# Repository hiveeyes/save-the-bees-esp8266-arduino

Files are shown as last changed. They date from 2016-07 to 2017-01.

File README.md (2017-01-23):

# Save the Bees! for ESP8266 (WeMos D1 Mini)

## Introduction
<!--A brief description of the purpose and functionality of the project.-->
*Save the Bees!* is an Open Source project that is used to track the status of a beehive through a microcontroller and some sensors.

The following version is the entry-level one and it is intended for the the ESP8266 microcontroller running the Arduino framework.

Following the steps of this guide you can start quickly tracking your beehive and get the status of it.

## Requirements
<!--A list of all system requirements and required third-party components.-->

### Hardware
This is your shopping list:

- Board: [WeMos D1 Mini](https://www.wemos.cc/product/d1-mini.html)
- Analog Multiplexer: [CD74HC4052E](http://www.ti.com/lit/gpn/CD74HC4052) by Texas Instruments
- RTC module: either [DS1307](https://www.maximintegrated.com/en/products/digital/real-time-clocks/DS1307.html) or [DS3231](https://www.maximintegrated.com/en/products/digital/real-time-clocks/DS3231.html) based modules are compatible
- Temperature module: [AM2315](http://www.aosong.com/en/products/details.asp?id=121) by Aosong
- Compression load cells: 4x [FC2231-0000-0100-L](http://www.te.com/usa-en/product-CAT-FSE0001.html) by Measurement Specialities

### Software
The Software used for this project and the source code of the project itself are open source and then free to use:

- USBtoUART drivers
- [PlatformIO](http://platformio.org/) IDE or [Arduino](https://www.arduino.cc/) IDE with support for the WeMos D1 Mini board
- Adafruit AM2315 [Library](https://github.com/adafruit/Adafruit_AM2315)
- Adafruit RTClib [Library](https://github.com/adafruit/RTClib)
- PubSubClient [Library](https://github.com/uberdriven/pubsubclient), an Arduino client for MQTT protocol, modified with an increased packet size of 512 bytes
- Arduino JSON [Library](https://github.com/bblanchon/ArduinoJson)

## Installation & Configuration
<!--Step-by-step instructions, with proper punctuation, on how to install and configure the project.-->
In order to compile the script and upload it to the board, you have to follow the next steps:

### 1) Download the CH340 USB to UART drivers
The drivers are necessary to communicate with the serial port on a device via USB. You can download the them from [here](https://www.wemos.cc/downloads/) for Windows or macOS. GNU/Linux systems do not need any driver.

NOTE: If you have **macOS Sierra** (10.12.x) and you never installed any CH34x drivers before, you must download [this](http://blog.sengotta.net/wp-content/uploads/2015/11/CH34x_Install_V1.3.zip) driver, otherwise if you had already a previous version installed follow [this](https://github.com/adrianmihalko/ch340g-ch34g-ch34x-mac-os-x-driver) guide.

To be sure that your drivers are currently working, connect the WeMos D1 Mini to your computer via USB, open a terminal window and type `ls /dev/cu.*` (in macOS). You should find between the devices connected something similar to `/dev/cu.wchusbserial1410`.

### 2) Install Python
Python is necessary because the compiler for the ESP8266 (on which the WeMos D1 mini is based) runs a set of commands in Python. Python comes by default with macOS and GNU/Linux, to check if it is installed, just open a terminal window and digit `python -V`. While Windows users should [download](https://www.python.org/downloads/) and install it manually.

### 3) Set up your IDE
There are two main options where to edit the script, send the code to the board and monitor the serial output: Arduino IDE or PlatformIO.

#### PlatformIO
PlatformIO is an open source ecosystem for IoT development. It brings many useful features as code auto completion, a smart library manager and others. Is is available as *core* version (command line interface) and as a plugin for many popular IDEs and text editors. It supports natively many platforms, frameworks and boards. The easiest way to start with PlatformIO is [download](http://platformio.org/get-started/ide) the PlatformIO IDE (Atom text editor with already the PlatformIO core and plugins installed).

#### Arduino IDE
The Arduino IDE is the native software for developing programs for Arduino and compatible boards.

- Download it for [Windows](https://www.arduino.cc/en/Guide/Windows), [macOS](https://www.arduino.cc/en/Guide/MacOSX) or [GNU/Linux](https://www.arduino.cc/en/Guide/Linux)
- Once downloaded and installed, open the `preferences` tab, and into the `Additional Board Manager` field insert `http://arduino.esp8266.com/stable/package_esp8266com_index.json`. The field can support multiple URLs separated with commas
- Open `Tools` → `Board: xxx` → `Boards Manager` and install *esp8266* by *ESP8266 Community*
- Select the right board:  `Tools` → `Board: xxx` and select `WeMos D1 R2 Mini`
- Select the right upload speed: `Tools` → `Upload Speed` → `115200`

### 4) Install the required libraries

#### With PlatformIO
Platformio provides a very good [library manager](http://platformio.org/lib) and it is very easy add a new library for a project. Open Atom, then `PlatformIO` tab → `Terminal` → `Toggle` and type:

```
pio lib -g install 773
```
this command install the Adafruit AM2315 Library,

```
pio lib -g install 64
```
this command install the Arduino JSON library,

```
pio lib -g install 83
```
this command install the Adafruit RTClib Library,

```
pio lib -g install https://github.com/uberdriven/pubsubclient
```
this command install the PubSubClient modified library.

#### With Arduino IDE
First you should download the four libraries from GitHub, then open the Arduino IDE, `Sketch` tab → `Include Library` → `Add .ZIP library` and select the downloaded libs one by one. For an extended explanation, check the Arduino [guide](https://www.arduino.cc/en/Guide/Libraries) how to include libraries.

### 5) Connect the componets
Connect the components as in the Fritzing generated PDF schema in this repo.

NOTE: if you use a DS1307 RTC, you should provide it 5V, while for a DS3231 RTC it is enough use the 3.3V.

### 6) Flash the program on your board
TO-DO

Connect your WeMos D1 Mini to your computer via USB. Now you can copy and paste from this repository the last version of the code.

For now, the only two parameters you can modify are:

- the `SLEEP_TIME`, that is the number of seconds for 
- the model of RTC used
- the `ACCESS_POINT_PWD`, that is the password of the setup mode, the default one is *BeeHive91*

### 7) Create your device on relayr Dashboard

### 8) Insert your Wi-Fi and relayr credentials
Turn on the board into the Setup Mode. It will create a Wi-Fi Access Point called `BeeSetup` using both the 2.4GHz and the 5GHz frequency bands. From your computer connect to that network using the password defined in the step 6 of this document. Then open your browser and in the URL field digit `192.168.1.4` and connect. You will see the following page:

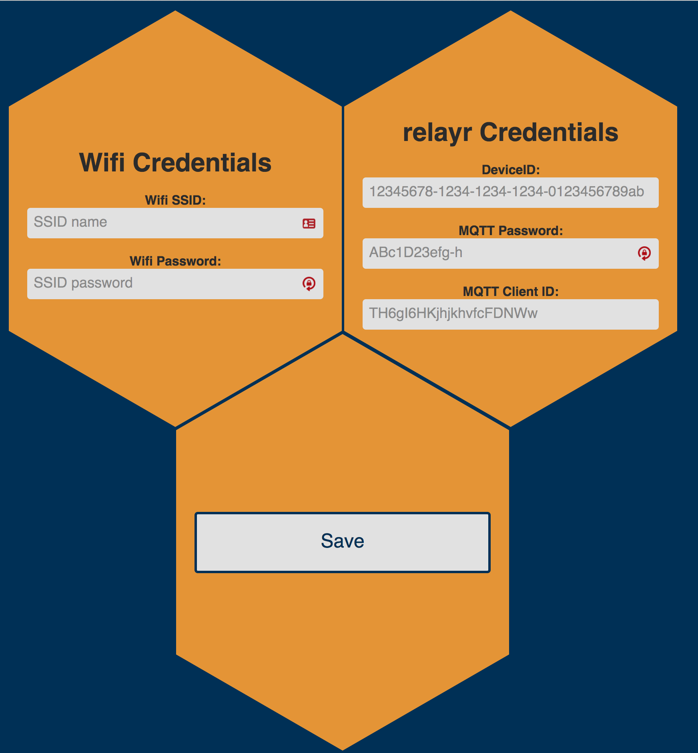
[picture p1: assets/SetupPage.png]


Enter first the Wi-Fi credentials of your Access Point connected to the Internet, then the relayr credentials you got from step 7 of this guide and finally press on the Save button. If in future you will have to change your parameters, just follow again this step.

### 9) Set the tare

Now digit in your browser the address `192.168.1.4/tare`. You will see the following page:

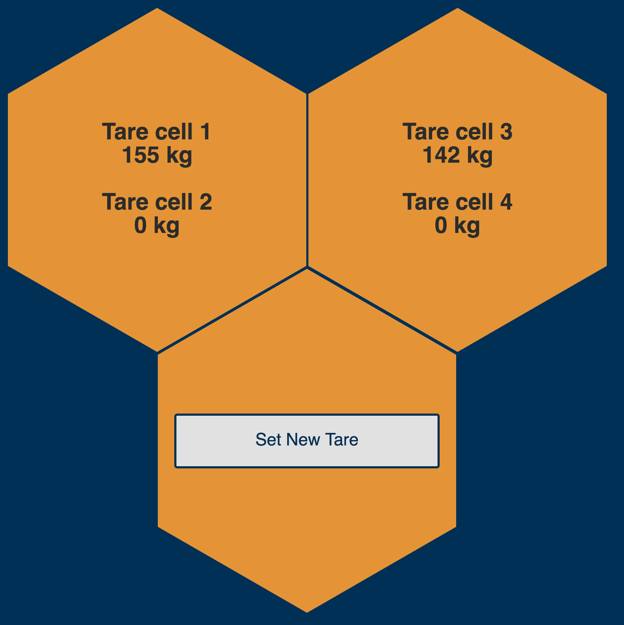
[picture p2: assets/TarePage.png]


When you will press the `Set New Tare` button the current weight on the loadcell will be considered the point zero.

### 10) (Optional) Display the beehive sensors readings with Grafana

## To-Do

- Add a switch to enter in setup mode easier
- Add configurations/commands/QoS support
- Build the base and hardware
- Add 5th loadcell support
- Add external ADC

## License
<!--The license under which the software will be released. Open-source projects MUST include the MIT License, and closed-source projects MUST include a proprietary license to be discussed with the Documentation team.
-->
The MIT License (MIT)
Copyright (c) 2017 relayr Inc., Riccardo Marconcini [riccardo DOT marconcini AT relayr DOT de](mailto:riccardo.marconcini@relayr.de)

Permission is hereby granted, free of charge, to any person obtaining a copy of this software and associated documentation files (the "Software"), to deal in the Software without restriction, including without limitation the rights to use, copy, modify, merge, publish, distribute, sublicense, and/or sell copies of the Software, and to permit persons to whom the Software is furnished to do so, subject to the following conditions:

The above copyright notice and this permission notice shall be included in all copies or substantial portions of the Software.

THE SOFTWARE IS PROVIDED "AS IS", WITHOUT WARRANTY OF ANY KIND, EXPRESS OR IMPLIED, INCLUDING BUT NOT LIMITED TO THE WARRANTIES OF MERCHANTABILITY, FITNESS FOR A PARTICULAR PURPOSE AND NONINFRINGEMENT. IN NO EVENT SHALL THE AUTHORS OR COPYRIGHT HOLDERS BE LIABLE FOR ANY CLAIM, DAMAGES OR OTHER LIABILITY, WHETHER IN AN ACTION OF CONTRACT, TORT OR OTHERWISE, ARISING FROM, OUT OF OR IN CONNECTION WITH THE SOFTWARE OR THE USE OR OTHER DEALINGS IN THE SOFTWARE.

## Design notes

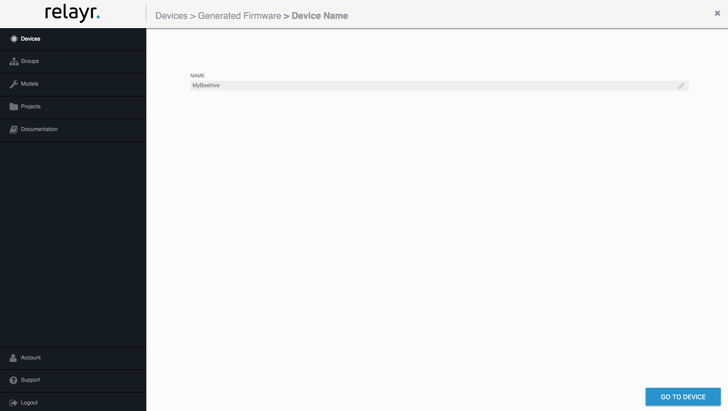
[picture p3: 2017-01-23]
assets/Schermata 2017-01-18 alle 18.39.31.png

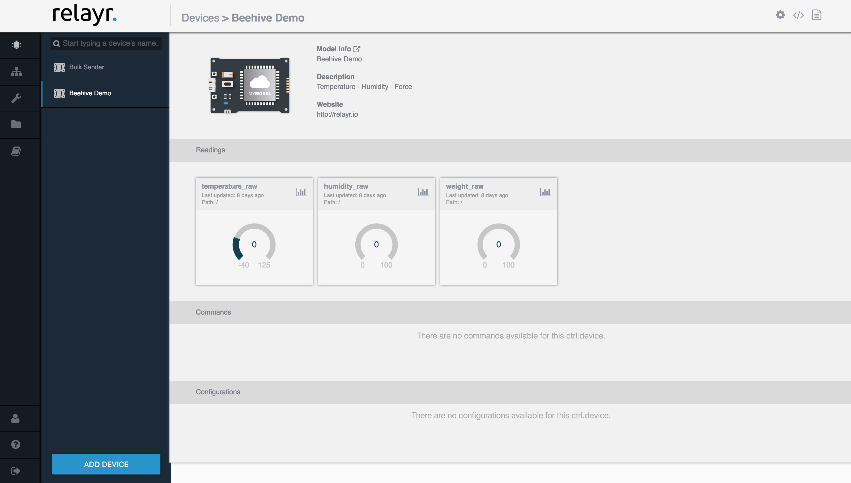
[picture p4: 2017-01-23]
assets/Schermata 2017-01-18 alle 18.28.16.png

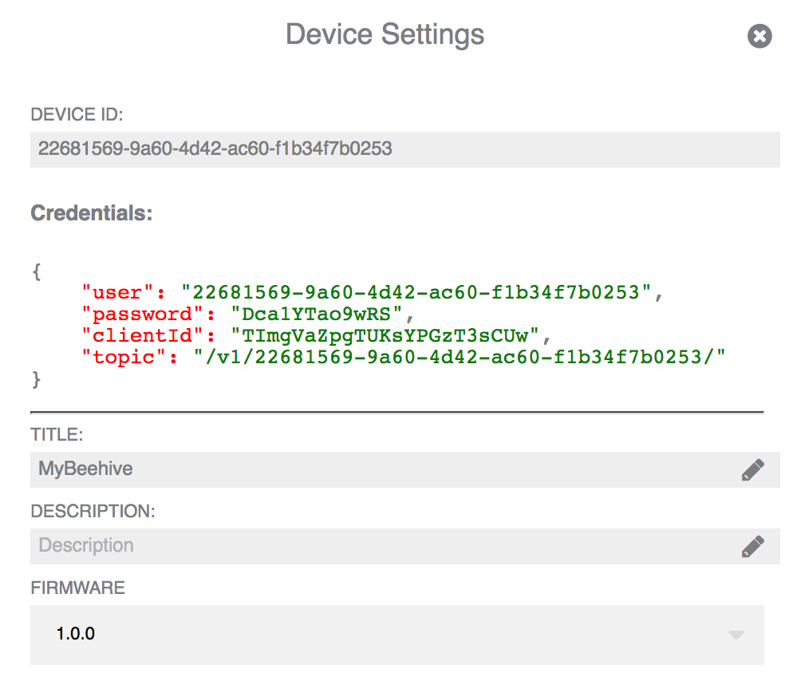
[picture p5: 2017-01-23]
assets/Schermata 2017-01-18 alle 18.40.48.png

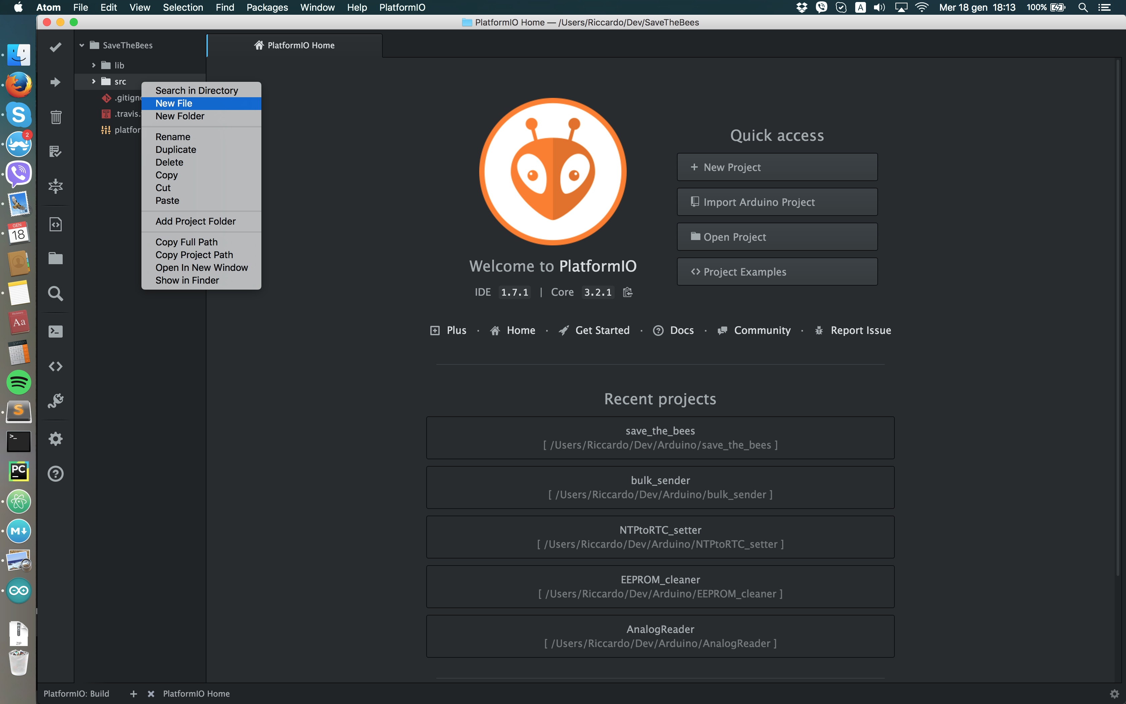
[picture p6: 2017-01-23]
assets/Schermata 2017-01-18 alle 18.13.08.png

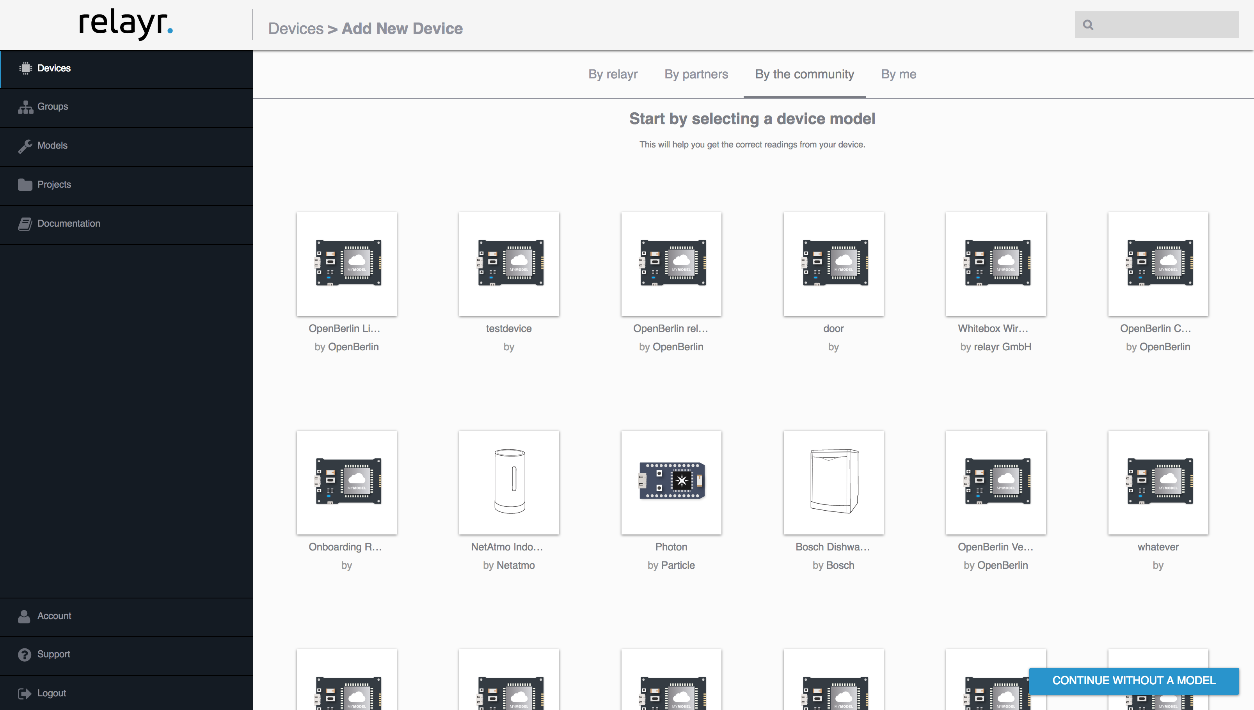
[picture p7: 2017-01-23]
assets/Schermata 2017-01-18 alle 18.37.14.png

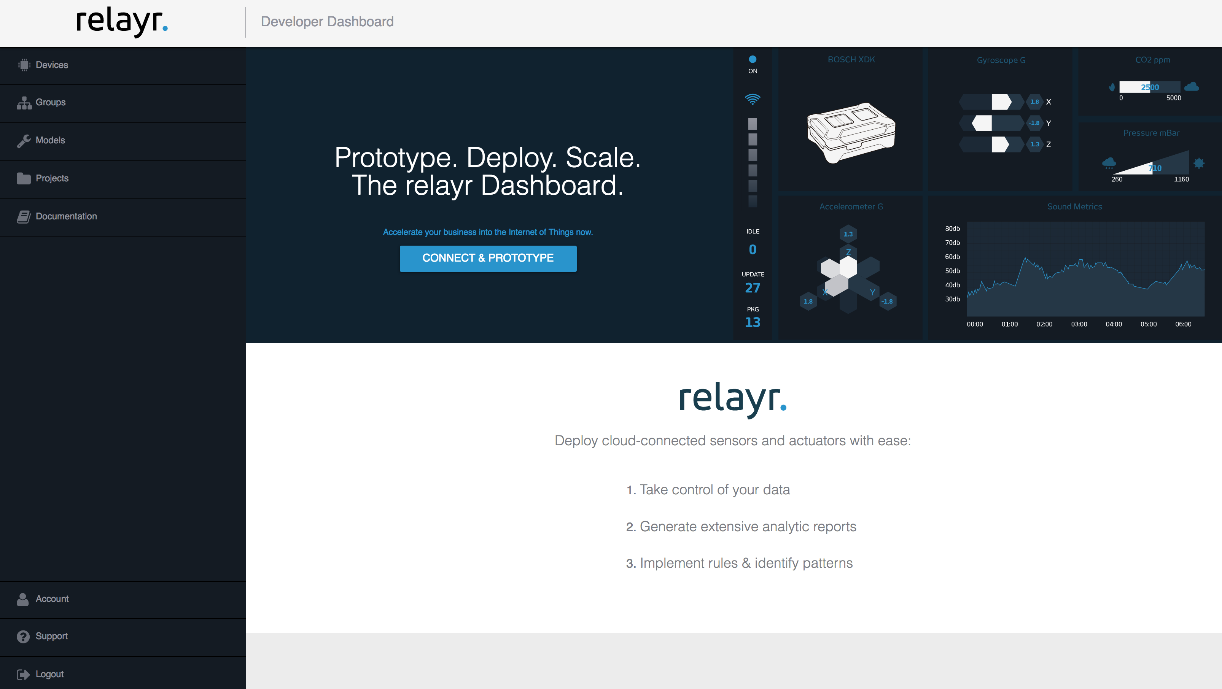
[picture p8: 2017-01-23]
assets/Schermata 2017-01-18 alle 18.27.46.png

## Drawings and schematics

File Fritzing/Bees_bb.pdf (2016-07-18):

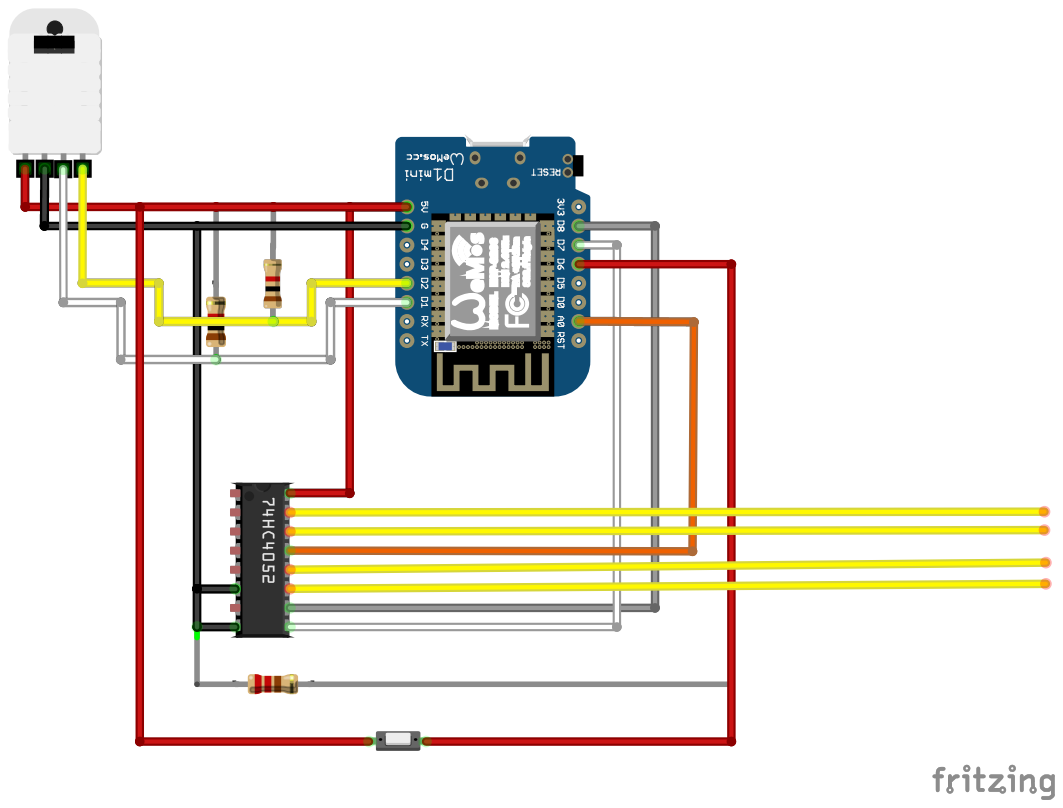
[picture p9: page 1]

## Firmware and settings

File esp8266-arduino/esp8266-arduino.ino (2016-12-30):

/*
 *   Save The Bees v1.0.0
 *
 */

/***************************************************************************************
**  Libraries **
***************************************************************************************/

#include <Adafruit_AM2315.h>
#include <Arduino.h>
#include <ArduinoJson.h>
#include <EEPROM.h>
#include <ESP8266WiFi.h>
#include <PubSubClient.h>
#include <RTClib.h>
#include <WiFiUdp.h>
#include <Wire.h>

/***************************************************************************************
**  Global Constants **
***************************************************************************************/

//  Credentials from the relayr developer dashboard
#define MQTT_SERVER "mqtt.relayr.io"

//  MQTT Params
#define MIN_PUBLISH_PERIOD 200
#define MQTT_PORT 1883

//  Bulk Params
#define BULK_DIM 60    //  Number of packet inside the bulk to send
#define PACKET_SIZE 10 //  Number of bytes used for each packet

//  Map of the EEPROM header
#define SSID_BYTE 0
#define SSID_PWD_BYTE 60
#define DEVICEID_BYTE 120
#define MQTT_PWD_BYTE 180
#define MQTT_CLIENTID_BYTE 240
#define TARE_BYTE 300
#define PACKET_CYCLE_BYTE 316
#define RTC_CYCLE_BYTE 318

//  Map of the packet bytes
#define TIMESTAMP_BYTE 320 //  Number of the first timestamp byte
#define TEMP_BYTE 324      //  Number of the first temperature
#define HUM_BYTE 326       //  Number of the humidity byte of the 1st packet
#define WEIGHT_BYTE 328

//  Deep Sleep Time in seconds
#define SLEEP_TIME 60

//  RTC will sync to NTP at the first connection after reached this cycle
#define RTC_CYCLE 10080

//  Size of flash memory
#define FLASH_SIZE 4096

//  Pin to change WiFi Mode
#define MODEPIN D5

// Pins for the Multiplexer & Loadcells
#define LOADPIN A0
#define TAREPIN D6
#define S0 D8
#define S1 D7

// Pins for AM2315
#define AM_SDA D4
#define AM_SCL D3

#define WEB_SERVER_PORT 80
#define ACCESS_POINT_SSID "BeeSetup"
#define ACCESS_POINT_PWD "BeeHive"
#define ACCESS_POINT_CHANNEL 1
#define ACCESS_POINT_HIDDEN false

/***************************************************************************************
**  Global Variables Function **
***************************************************************************************/

WiFiServer server(WEB_SERVER_PORT);
WiFiClient espClient;
PubSubClient pubSubClient(espClient);
RTC_DS1307 rtc;
Adafruit_AM2315 am2315;

static WiFiUDP udp;
const int led = BUILTIN_LED;
bool ledState = LOW;
unsigned long lastPublishTime;
unsigned long lastBlinkTime;
int publishingPeriod = 3000;
uint16_t humidity, temperature, weight;
float humidity_tmp, temperature_tmp, weight_tmp;
unsigned long unixTime;
short currentCycle;
long currentRTCCycle;
bool defaultMode;
char SSID[60];
char SSID_password[60];
char device_ID[60];
char MQTT_password[60];
char MQTT_clientID[60];
int loadArray[4];
int tareArray[4];

/***************************************************************************************
**  Functions Declaration **
***************************************************************************************/

void setup_wifi();
void setupServer();
void publish_packet(uint8_t packet_number);
void publish(long tmp_unixTime, short tmp_temp, short tmp_hum);
void callback(char *topic, byte *payload, unsigned int length);
void handlePayload(char *payload);
void mqtt_connect();
void blink(int interval);
void load_sensors();
unsigned long ntpUnixTime(UDP &udp);
void EEPROMWriteLong(int address, long value);
long EEPROMReadLong(long address);
void EEPROMWriteInt(int address, int value);
long EEPROMReadInt(int address);

void getTempHumiReadings();
void getLoadReadings();
void setTare();
float calibrate();

/***************************************************************************************
**  Setup Function **
***************************************************************************************/

void setup() {

  //  Initialize the PINS
  pinMode(led, OUTPUT);
  // pinMode(AM_SDA, INPUT_PULLUP);
  // pinMode(AM_SCL, INPUT_PULLUP);
  pinMode(S0, OUTPUT);
  pinMode(S1, OUTPUT);
  pinMode(LOADPIN, INPUT);
  pinMode(TAREPIN, INPUT);
  pinMode(MODEPIN, INPUT);

  //  Initialize the EEPROM
  EEPROM.begin(FLASH_SIZE);

  //  Initialize the Serial output
  Serial.begin(9600);
  Serial.println("\n\n");
  Serial.println("*** Save The Bees v.1.0.0 ***");

  // Check in which mode is the node and execute appropriate setup.
  defaultMode = digitalRead(MODEPIN);

  if (!defaultMode) {
    Serial.println("Setup mode active");
    setupServer();

  } else {

    Serial.println("Default mode active");

    //  Check if RTC is connected via I2C
    while (true) {
      if (!rtc.begin()) {
        Serial.println("RTC module not found... Retrying");
      } else
        break;
    }

    while (true) {
      if (!am2315.begin()) {
        Serial.println("AM2315 module not found... Retrying");
      } else
        break;
    }

    Serial.println("Modules initialized");

    //  Force the WiFi off to avoid the troubles of wifi after woke up from deep
    //  sleep with a I2C device connected
    WiFi.mode(WIFI_OFF);

    //  Read the cycle counters from EEPROM
    currentCycle = EEPROMReadInt(PACKET_CYCLE_BYTE);
    currentRTCCycle = EEPROMReadLong(RTC_CYCLE_BYTE);

    //  Read the vriables from EEPROM
    EEPROM.get(TARE_BYTE, tareArray);

    //  In case of flashing a scipt with reduced BULK DIM than the previous
    //  flashed version, set counter to zero
    if (currentCycle > BULK_DIM) {
      currentCycle = 0;
    }

    if (currentCycle < BULK_DIM) {

      Serial.print("Packet number: ");
      Serial.print(currentCycle + 1);
      Serial.print(" of ");
      Serial.println(BULK_DIM);

      Serial.print("RTC cycle: ");
      Serial.print(currentRTCCycle + 1);
      Serial.print(" of ");
      Serial.println(RTC_CYCLE);

      if (currentRTCCycle >= RTC_CYCLE)
        Serial.println(
            "The RTC time will be adjusted during next internet connection");

      // Get data from sensors
      load_sensors();
      getLoadReadings();

      //  Get the timestamp from RTC module
      unixTime = rtc.now().unixtime();
      Serial.print("RTC time: ");
      Serial.println(unixTime);

      //  Save the readings and the timestamp into the EEPROM
      EEPROMWriteLong(TIMESTAMP_BYTE + (currentCycle * PACKET_SIZE), unixTime);
      EEPROMWriteInt(TEMP_BYTE + (currentCycle * PACKET_SIZE), temperature);
      EEPROMWriteInt(HUM_BYTE + (currentCycle * PACKET_SIZE), humidity);
      EEPROMWriteInt(WEIGHT_BYTE + (currentCycle * PACKET_SIZE), weight);

      Serial.println("Data saved into the EEPROM");

      //  Increment the counters
      currentCycle++;
      currentRTCCycle++;

      // If the packet just saved is not the last of the bulk, I save the cycle
      // number
      if (currentCycle != BULK_DIM) {
        EEPROMWriteInt(PACKET_CYCLE_BYTE, currentCycle);
        EEPROMWriteLong(RTC_CYCLE_BYTE, currentRTCCycle);
        EEPROM.end();
      }

      //  If the packet just saved is the last one, send all the data in bulk
      else {

        //  Read Params from EEPROM
        EEPROM.get(SSID_BYTE, SSID);
        EEPROM.get(SSID_PWD_BYTE, SSID_password);

        //  Initializing WiFi
        setup_wifi();

        //  Check if the RTC should be adjusted
        if (currentRTCCycle >= RTC_CYCLE) {
          delay(500);

          long NTPtime = 0;

          while (true) {
            delay(2000);
            NTPtime = ntpUnixTime(udp);
            Serial.print("NTP Time: ");
            Serial.println(NTPtime);
            if (NTPtime != 0)
              break;
          }

          //  Adjust RTC Module
          rtc.adjust(DateTime(NTPtime));
          Serial.println("RTC time just adusted with NTP time");

          //  Clear RTC counter
          EEPROMWriteLong(RTC_CYCLE_BYTE, 0);
        }

        //  Establish the connection to MQTT server
        EEPROM.get(DEVICEID_BYTE, device_ID);
        EEPROM.get(MQTT_PWD_BYTE, MQTT_password);
        EEPROM.get(MQTT_CLIENTID_BYTE, MQTT_clientID);

        pubSubClient.setServer(MQTT_SERVER, MQTT_PORT);
        pubSubClient.setCallback(callback);
        publishingPeriod = publishingPeriod > MIN_PUBLISH_PERIOD
                               ? publishingPeriod
                               : MIN_PUBLISH_PERIOD;
        mqtt_connect();

        // Cycle that publishes all the packets stored into the EEPROM
        for (int i = 0; i < BULK_DIM; i++) {
          publish_packet(i);
          delay(500);
        }

        //  After sent all packets, the packet counter is set to 0
        Serial.println("Clearing EEPROM");
        EEPROMWriteInt(PACKET_CYCLE_BYTE, 0);
        EEPROM.end();
      }

      Serial.println("Going to sleep... Zzz");

      //  Yield function to give time to finish executing all background
      //  processes
      yield();

      //  Setting the deep sleep time
      ESP.deepSleep(SLEEP_TIME * 1000000);
    }
  }
}
/***************************************************************************************
**  Loop Function **
***************************************************************************************/

void loop() {
  if (!defaultMode) {
    runServer();
  }
}

/***************************************************************************************
**  Setup WiFi Function **
***************************************************************************************/

void setup_wifi() {
  delay(500);

  Serial.println("");
  Serial.print("Connecting to ");
  Serial.println(SSID);

  WiFi.mode(WIFI_STA);
  WiFi.begin(SSID, SSID_password);

  int count = 0;

  while (WiFi.status() != WL_CONNECTED) {
    delay(1000);
    Serial.print(".");
    count++;

    if (count > 15) {
      WiFi.mode(WIFI_OFF);
      delay(500);
      WiFi.mode(WIFI_STA);
      WiFi.begin(SSID, SSID_password);
      count = 0;
      delay(1000);
    }
  }

  Serial.println("");
  Serial.println("WiFi connected");
  Serial.print("IP address: ");
  Serial.println(WiFi.localIP());
}

/***************************************************************************************
**  Publish Packet Function **
***************************************************************************************/

void publish_packet(int packet_number) {

  //  Check the connection before publish
  if (pubSubClient.connected()) {

    Serial.println("");
    Serial.println("Start publishing...");
    delay(3000);

    //  Publish within the defined publishing period
    if (millis() - lastPublishTime > publishingPeriod) {

      lastPublishTime = millis();
      delay(100);

      long tmp_unixTime =
          EEPROMReadLong(TIMESTAMP_BYTE + (packet_number * PACKET_SIZE));
      short tmp_temp = EEPROMReadInt(TEMP_BYTE + (packet_number * PACKET_SIZE));
      short tmp_hum = EEPROMReadInt(HUM_BYTE + (packet_number * PACKET_SIZE));
      short tmp_weight =
          EEPROMReadInt(WEIGHT_BYTE + (packet_number * PACKET_SIZE));

      publish(tmp_unixTime, tmp_temp, tmp_hum, tmp_weight);

      Serial.print("Just published packet number ");
      Serial.println(packet_number + 1);
      Serial.println("");
    }

    //  Blink LED
    blink(publishingPeriod / 2);
  }

  else {
    Serial.println("Connection not available: retrying...");
    mqtt_connect();
  }
}

/***************************************************************************************
**  Publish Function **
***************************************************************************************/

void publish(long tmp_unixTime, short tmp_temp, short tmp_hum,
             short tmp_weight) {

  //  Create the JSON containing the data
  StaticJsonBuffer<MQTT_MAX_PACKET_SIZE> pubJsonBuffer;
  JsonArray &root = pubJsonBuffer.createArray();

  //  Timestamp of the readings needs to be specified in milliseconds but ESP
  //  cannot handle 64bits types, so it is transformed in string
  String ut = (String(tmp_unixTime) + String("000"));

  //  First object: temperature
  JsonObject &leaf1 = root.createNestedObject();
  leaf1["ts"] = ut;
  leaf1["meaning"] = "temperature_raw";
  leaf1["value"] = tmp_temp;

  //  Second object: humidity
  JsonObject &leaf2 = root.createNestedObject();
  leaf2["ts"] = ut;
  leaf2["meaning"] = "humidity_raw";
  leaf2["value"] = tmp_hum;

  //  Third object: weight
  JsonObject &leaf3 = root.createNestedObject();
  leaf2["ts"] = ut;
  leaf2["meaning"] = "weight_raw";
  leaf2["value"] = tmp_weight;

  //  Creating MQTT packet
  char message_buff[MQTT_MAX_PACKET_SIZE];
  root.printTo(message_buff, sizeof(message_buff));

  char mess_new[MQTT_MAX_PACKET_SIZE];

  //  Mapping the JSON string and removing the " " from the timestamp field
  //  since it was treated as a string
  int idxToDel = 7;
  memmove(&message_buff[idxToDel], &message_buff[idxToDel + 1],
          strlen(message_buff) - idxToDel);
  idxToDel = 20;
  memmove(&message_buff[idxToDel], &message_buff[idxToDel + 1],
          strlen(message_buff) - idxToDel);
  idxToDel = 69;
  memmove(&message_buff[idxToDel], &message_buff[idxToDel + 1],
          strlen(message_buff) - idxToDel);
  idxToDel = 82;
  memmove(&message_buff[idxToDel], &message_buff[idxToDel + 1],
          strlen(message_buff) - idxToDel);

  // Publish the MQTT packet
  char dataTopic[45];
  sprintf(dataTopic, "/v1/%s/data", device_ID);

  pubSubClient.publish(dataTopic, message_buff);
  Serial.println("Publishing " + String(message_buff));
}

//------------------------------------------------------------------------------------//
// Enduser wifi and relayr setup functions. //
//------------------------------------------------------------------------------------//

void setupServer() {

  // Setup the access point
  WiFi.mode(WIFI_AP);

  Serial.print("Setting WEMOS as Soft Access Point... ");
  /*boolean result = WiFi.softAP("BeeSetup");
     if (result == true)
     Serial.println("Done");
     else
     Serial.println("Failed!");*/
  WiFi.softAP("BeeSetup");

  // Start the server
  server.begin();
  Serial.println("WebServer started");

  // Print the IP address.
  Serial.print("Access the Web Server at http://");
  Serial.print(WiFi.softAPIP());
  Serial.println("/");
}

void runServer() {

  // Check if a client has connected
  WiFiClient wifiClient = server.available();
  if (!wifiClient) {
    return;
  }

  // Wait until the client sends some data
  while (!wifiClient.available()) {
    delay(1000);
    Serial.print("Server not running yet");
  }

  // Read and parse the request.
  String request = wifiClient.readString();
  parseClientRequest(request);
  wifiClient.flush();

  // Return the response
  wifiClient.println("HTTP/1.1 200 OK");
  wifiClient.println("Content-Type: text/html");
  wifiClient.println("");
  wifiClient.println(
      "<!DOCTYPE html><html><head> <title>Save The Bees</title> <style>body { "
      "background: #003056; font-family: Helvetica, Arial, sans-serif; color: "
      "#2B2B2B}.hexagon:before { content: ''; width: 0; height: 0; "
      "border-bottom: 120px solid #e49436; border-left: 208px solid "
      "transparent; border-right: 208px solid transparent; position: absolute; "
      "top: -120px}.hexagon { width: 416px; height: 280px; margin-top: 124px; "
      "margin-left: 3px; background-color: #e49436; position: relative; float: "
      "left}.hexagon:after { content: ''; width: 0; position: absolute; "
      "bottom: -120px; border-top: 120px solid #e49436; border-left: 208px "
      "solid transparent; border-right: 208px solid transparent}.hexagon-row { "
      "clear: left}.hexagon-row.even { margin-left: 209px}.hexagonIn { width: "
      "370px; text-align: center; position: absolute; top: 50%; left: 50%; "
      "transform: translate(-50%, -50%)}.input { color: #3c3c3c; font-family: "
      "Helvetica, Arial, sans-serif; font-weight: 500; font-size: 18px; "
      "border-radius: 4px; line-height: 22px; background-color: #E1E1E1; "
      "padding: 5px 5px 5px 5px; margin-bottom: 5px; width: 100%; box-sizing: "
      "border-box; border: 3px solid #E1E1E1}.input:focus { background: "
      "#E1E1E1; box-shadow: 0; border: 3px solid #003056; color: #003056; "
      "outline: none; padding: 5px 5px 5px 5px;}#button { font-family: "
      "Helvetica, sans-serif; float: left; width: 100%; cursor: pointer; "
      "background-color: #E1E1E1; color: #003056; border: #003056 solid 3px; "
      "font-size: 24px; padding-top: 22px; padding-bottom: 22px; transition: "
      "all 0.3s; margin-top: 0px; border-radius: 4px}#button:hover { "
      "background-color: #003056; color: #E1E1E1; border: #E1E1E1 solid "
      "3px}</style></head><body> <form id='credentialsForm' action=''> <div "
      "class='hexagon-row'> <div class='hexagon'> <div class='hexagonIn'> "
      "<h1>Wifi Credentials</h1> <b>Wifi SSID:</b> <br> <input type='text' "
      "class='input' name='SSID' placeholder='SSID name' value='" +
      String(SSID) + "'> <br><br> <b>Wifi Password:</b> <br> <input "
                     "type='password' class='input' name='SSID_password' "
                     "placeholder='SSID password' value='" +
      String(SSID_password) +
      "'> </div> </div> <div class='hexagon'> <div class='hexagonIn'> "
      "<h1>relayr Credentials</h1> <b>DeviceID:</b> <br> <input type='text' "
      "class='input' name='device_ID' "
      "placeholder='12345678-1234-1234-1234-0123456789ab' value='" +
      String(device_ID) + "'> <br><br> <b>MQTT Password:</b> <br> <input "
                          "type='password' class='input' name='MQTT_password' "
                          "placeholder='ABc1D23efg-h' value='" +
      String(MQTT_password) + "'> <br><br> <b>MQTT Client ID:</b> <br> <input "
                              "type='password' class='input' "
                              "name='MQTT_clientID' "
                              "placeholder='TH6gI6HKjhjkhvfcFDNWw' value='" +
      String(MQTT_clientID) +
      "'> </div> </div> </div> <div class='hexagon-row even'> <div "
      "class='hexagon'> <div class='hexagonIn'> <input type='submit' "
      "id='button' value='Save'> </div> </div> </div> </form></body></html>");
  delay(1);
}

void parseClientRequest(String req) {

  // Get the SSID, PASSWORD, RELAYRUSER and RELAYRPASSWORD.
  int startIndex = req.indexOf("GET /?SSID=");

  // First check if request contains 'SSID='.
  if (startIndex != -1) {

    // If so parse/search for all the other points of interest.
    int endIndex = req.indexOf("&SSID_password=");
    req.substring(startIndex + 11, endIndex).toCharArray(SSID, 60);

    // Get the PASSWORD.
    startIndex = req.indexOf("&SSID_password=");
    endIndex = req.indexOf("&device_ID=");
    req.substring(startIndex + 15, endIndex).toCharArray(SSID_password, 60);

    // Get the RELAYRUSER.
    startIndex = req.indexOf("&device_ID=");
    endIndex = req.indexOf("&MQTT_password=");
    req.substring(startIndex + 11, endIndex).toCharArray(device_ID, 60);

    // Get the RELAYRPASSWORD.
    startIndex = req.indexOf("&MQTT_password=");
    endIndex = req.indexOf("&MQTT_clientID=");
    req.substring(startIndex + 15, endIndex).toCharArray(MQTT_password, 60);

    // Get the RELAYRPASSWORD.
    startIndex = req.indexOf("&MQTT_clientID=");
    endIndex = req.indexOf(" HTTP/");
    req.substring(startIndex + 15, endIndex).toCharArray(MQTT_clientID, 60);

    // Debug. //
    Serial.println("-----------------");
    Serial.println(SSID);
    Serial.println(SSID_password);
    Serial.println(device_ID);
    Serial.println(MQTT_password);
    Serial.println(MQTT_clientID);
    Serial.println("-----------------");
    // ----- //

    EEPROM.put(SSID_BYTE, SSID);
    EEPROM.put(SSID_PWD_BYTE, SSID_password);
    EEPROM.put(DEVICEID_BYTE, device_ID);
    EEPROM.put(MQTT_PWD_BYTE, MQTT_password);
    EEPROM.put(MQTT_CLIENTID_BYTE, MQTT_clientID);
  }
}

/***************************************************************************************
**  Write/Read EEPROM Functions **
***************************************************************************************/

//  Write a Long into the EEPROM: write in the address byte and the next 3 ones
void EEPROMWriteLong(int address, long value) {

  byte four = (value & 0xFF);
  byte three = ((value >> 8) & 0xFF);
  byte two = ((value >> 16) & 0xFF);
  byte one = ((value >> 24) & 0xFF);

  EEPROM.write(address, four);
  EEPROM.write(address + 1, three);
  EEPROM.write(address + 2, two);
  EEPROM.write(address + 3, one);
  EEPROM.commit();
}

//  Read a Long from the EEPROM: read the address byte and the next 3 ones
//  returning the value
long EEPROMReadLong(long address) {
  long four = EEPROM.read(address);
  long three = EEPROM.read(address + 1);
  long two = EEPROM.read(address + 2);
  long one = EEPROM.read(address + 3);
  return ((four << 0) & 0xFF) + ((three << 8) & 0xFFFF) +
         ((two << 16) & 0xFFFFFF) + ((one << 24) & 0xFFFFFFFF);
}

// Write a Integer into the EEPROM: write in the address byte and the next one
void EEPROMWriteInt(int address, int value) {
  byte two = (value & 0xFF);
  byte one = ((value >> 8) & 0xFF);
  EEPROM.write(address, two);
  EEPROM.write(address + 1, one);
  EEPROM.commit();
}

//  Read a Integer from the EEPROM: read the address byte and the next one
//  returning the value
long EEPROMReadInt(int address) {
  int two = EEPROM.read(address);
  int one = EEPROM.read(address + 1);
  return ((two << 0) & 0xFF) + ((one << 8) & 0xFFFF);
}

/***************************************************************************************
**  NTP Function (from http://playground.arduino.cc/Code/NTPclient) **
***************************************************************************************/
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

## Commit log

2016-07-18 * Initial commit.
    [Bees.fzz]
2017-01-10 Add password to AP mode, bugfixes and code clean
    [save_the_bees.ino]
2017-01-11 Fixed bugs with URL ecoding in setup mode
    [save_the_bees.ino]
2017-02-08 Added ADC support, fifth loadcell and bugfixes.
    [save_the_bees.ino]
